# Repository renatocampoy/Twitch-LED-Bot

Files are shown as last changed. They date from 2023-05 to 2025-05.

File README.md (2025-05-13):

## Twitch LED Bot - ESP8266

Criado por Eng. Renato Campoy.

Este projeto permite que você controle um strip de LED NeoPixel via comandos no chat da Twitch, utilizando a placa ESP8266. O código é escrito em C++ e utiliza a biblioteca WiFiManager para gerenciar a conexão Wi-Fi e a biblioteca Adafruit NeoPixel para controlar o strip de LED.

<p float="center">
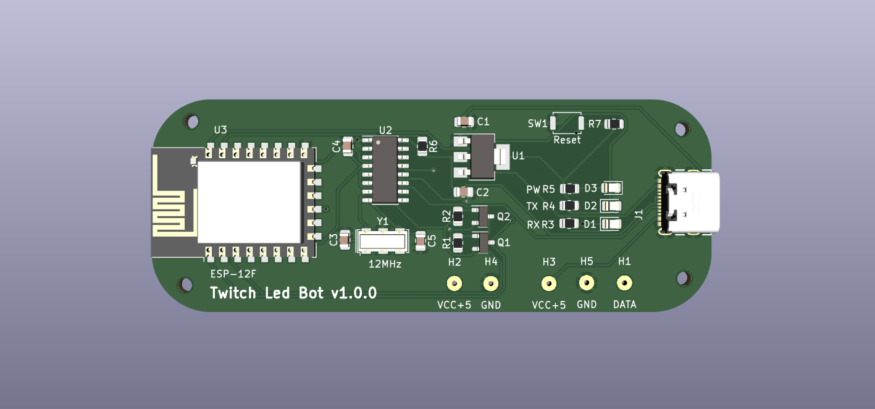
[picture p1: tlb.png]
 
</p>

## Token da Twitch

Para usar este código, você precisará de um token de OAuth da Twitch. Aqui estão as etapas para obtê-lo:

1.  Acesse [https://twitchapps.com/tmi/](https://twitchapps.com/tmi/)
2.  Clique em 'Connect' e autorize o acesso ao seu canal.
3.  Copie o token gerado. Este é o seu token OAuth, que permite que o bot envie mensagens ao seu canal.

Tenha em mente que este token é equivalente à senha da sua conta da Twitch. Não compartilhe com ninguém.

### Dependências

Você precisará das seguintes bibliotecas para usar este projeto:

-   ESP8266WiFi
-   DNSServer
-   ESP8266WebServer
-   WiFiManager
-   EEPROM
-   Adafruit_NeoPixel

Estas bibliotecas podem ser instaladas através do Gerenciador de Bibliotecas do Arduino.

## Instalação

1.  Clone este repositório.
2.  Abra o arquivo `.ino` no Arduino IDE.
3.  Carregue o código para o ESP8266.

## Configuração

1.  Ao ligar o ESP, uma rede wifi com o nome LEDBOT_AP aparecerá, conecte-se a ela.
2.  Ao conectar, aparecerá uma pagina onde você deve clicar em "Configure WIFI"
3.  Clique na sua REDE, entre com a senha.
4. Em "Nick" é o seu usuário da Twitch tudo em minúsculo 
5. Em Token você vai colocar o token gerado no tópico "Token da Twitch"

## Uso

Uma vez que o código esteja funcionando, você poderá enviar comandos para o chat da Twitch para controlar a iluminação do strip de LED. Aqui estão alguns exemplos de comandos que você pode usar:

-   `!led vermelho`: muda a cor do LED para vermelho.
-   `!led #ff00ff`: muda a cor do LED para o valor hexadecimal fornecido (neste caso, magenta).
-   `!led cores`: lista todas as cores disponíveis.

Além disso, o bot responde a comandos enviados via interface serial para reiniciar o ESP ou redefinir as configurações de WiFi ou Twitch. (vide código)

## Contribuição

Este é um projeto open-source. Se tiver alguma sugestão ou melhoria, por favor, faça um fork do repositório e envie uma pull request.

## Problemas Conhecidos

Atualmente, o bot não responde a erros do servidor da Twitch. Se você experimentar algum problema, tente reiniciar o ESP.

## Licença

Este projeto está licenciado sob a Licença GPLv3 - veja o arquivo [LICENSE](https://www.gnu.org/licenses/gpl-3.0.pt-br.html) para mais detalhes.

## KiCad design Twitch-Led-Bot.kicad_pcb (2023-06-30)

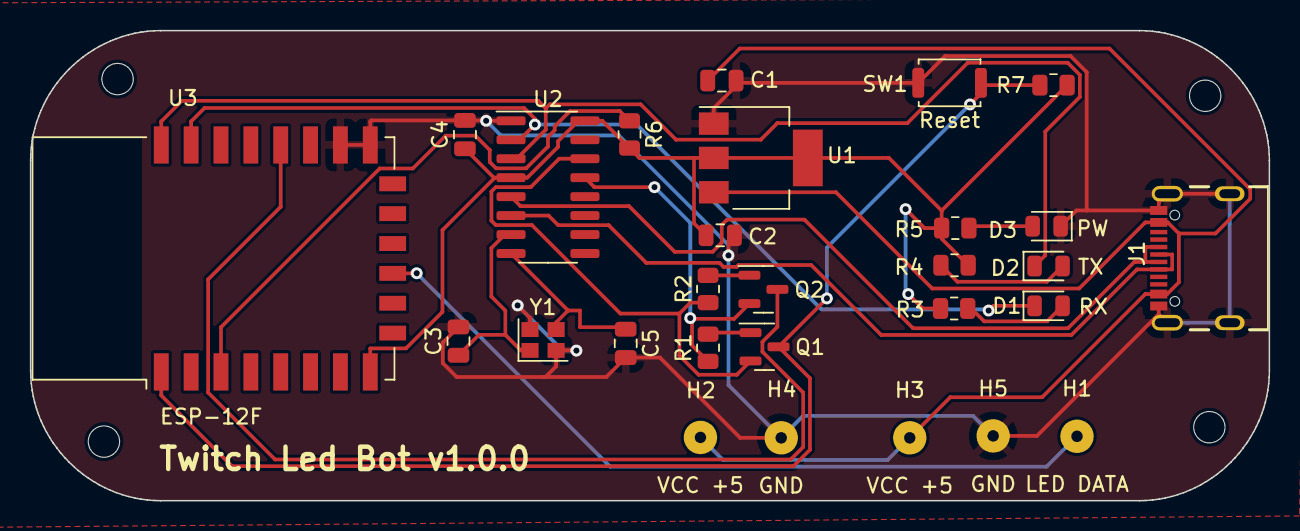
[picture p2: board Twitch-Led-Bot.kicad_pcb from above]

Board: 2 copper layers, 83.0 x 31.5 mm, 28 parts (0 on the bottom side), 20 nets.

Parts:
C1, C4: 10u; C_0805_2012Metric
C2: 100u; C_0805_2012Metric
C3, C5: 22p; C_0805_2012Metric
D1: RX; LED_0805_2012Metric
D2: TX; LED_0805_2012Metric
D3: PW; LED_0805_2012Metric
H1: LED DATA; MountingHole_2.1mm
H2, H3: VCC +5; MountingHole_2.1mm
H4, H5: GND; MountingHole_2.1mm
J1: USB4105-GF-A; GCT_USB4105-GF-A
Q1, Q2: BC847; SOT-23
R1, R2, R6, R7: 10K; R_0805_2012Metric
R3, R4, R5: 470; R_0805_2012Metric
SW1: Reset; SW_Push_SPST_NO_Alps_SKRK
U1: AMS1117-3.3; SOT-223-3_TabPin2
U2: CH340G; SOIC-16_3.9x9.9mm_P1.27mm
U3: ESP-12F; ESP-12E
Y1: 12MHz; Crystal_SMD_2520-4Pin_2.5x2.0mm

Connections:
+3V3: C2.1, C4.1, R3.2, R4.2, R5.2, R6.2, R7.2, U1.2 (VO), U2.4 (V3), U2.16 (VCC), U3.8 (VCC)
+5V: C1.1, H2.1, H3.1, J1.A4_B9 (VBUS), J1.B4_A9 (VBUS), U1.3 (VI)
CH_PD: R6.1, U3.3 (EN)
D+: J1.A6 (DP1), J1.B6 (DP2), U2.5 (UD+)
D-: J1.A7 (DN1), J1.B7 (DN2), U2.6 (UD-)
DTR: Q2.2 (E), R1.1, U2.13 (~DTR)
GND: C1.2, C2.2, C3.2, C4.2, C5.2, D3.1 (K), H4.1, H5.1, J1.A1_B12 (GND), J1.B1_A12 (GND), J1.S1 (SHELL_GND), J1.S2 (SHELL_GND), J1.S3 (SHELL_GND), J1.S4 (SHELL_GND), SW1.1, U1.1 (GND), U2.1 (GND), U3.15 (GND), U3.16 (GPIO15), Y1.2, Y1.4
IO0: Q2.3 (C), U3.18 (GPIO0)
IO9: H1.1, U3.11 (GPIO9)
unnamed: C3.1, U2.7 (XI), Y1.1
unnamed: C5.1, U2.8 (XO), Y1.3
unnamed: D1.2 (A), R3.1
unnamed: D2.2 (A), R4.1
unnamed: D3.2 (A), R5.1
unnamed: Q1.1 (B), R1.2
unnamed: Q2.1 (B), R2.2
RST: Q1.3 (C), R7.1, SW1.2, U3.1 (~RST)
RTS: Q1.2 (E), R2.1, U2.14 (~RTS)
RX: D1.1 (K), U2.2 (TXD), U3.21 (GPIO3/RXD)
TX: D2.1 (K), U2.3 (RXD), U3.22 (GPIO1/TXD)

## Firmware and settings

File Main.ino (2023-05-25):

/*
 * Twitch LED Bot - ESP8266
 * 
 * Desenvolvido por: Eng. Renato Campoy - http://campoy.eng.br
 * Versão: 1.0.0
 * Data: 25/05/2023
 * 
 * Licença: GPLv3
 * 
 * O código é livre para ser usado, modificado e distribuído,
 * desde que a atribuição seja feita ao autor original.
 */

#include <ESP8266WiFi.h>  // Importa a biblioteca para WiFi do ESP8266
#include <DNSServer.h>  // Importa a biblioteca para DNS Server
#include <ESP8266WebServer.h>  // Importa a biblioteca para Web Server do ESP8266
#include <WiFiManager.h>  // Importa a biblioteca para gerenciamento de WiFi
#include <EEPROM.h>  // Importa a biblioteca para armazenamento EEPROM
#include <Adafruit_NeoPixel.h>  // Importa a biblioteca para controle de LEDs NeoPixel

#define EEPROM_SIZE 512  // Define o tamanho da EEPROM
#define LED_PIN D8  // Define o pino onde o LED está conectado
#define LED_COUNT 200  // Define o número de LEDs no strip

// Define uma estrutura para armazenar as credenciais da Twitch
struct {
  char nick[40];
  char token[40];
}
eepromData;

// Define os parâmetros do WiFi Manager para configurar as credenciais da Twitch
WiFiManagerParameter customNick("nick", "Nick", "", 40);
WiFiManagerParameter customToken("token", "Token", "", 40);

// Define as configurações do servidor da Twitch
const char * server = "irc.chat.twitch.tv";
const int port = 6667;

// Define o cliente WiFi e o WiFi Manager
WiFiClient client;
WiFiManager wifiManager;

// Define a configuração do strip de LEDs
Adafruit_NeoPixel strip(LED_COUNT, LED_PIN, NEO_GRB + NEO_KHZ800);

// Função de callback para salvar as configurações na EEPROM quando a configuração do WiFi for concluída
void saveConfigCallback() {
  Serial.println("Deveria salvar para a EEPROM agora");

  strcpy(eepromData.nick, customNick.getValue());  // Copia o nick da Twitch para a estrutura
  strcpy(eepromData.token, customToken.getValue());  // Copia o token da Twitch para a estrutura

  EEPROM.put(0, eepromData);  // Grava a estrutura na EEPROM
  EEPROM.commit();  // Comita as alterações na EEPROM
}

// Configuração inicial do ESP8266
void setup() {
  Serial.begin(115200);  // Inicia a comunicação serial
  EEPROM.begin(EEPROM_SIZE);  // Inicia a EEPROM

  EEPROM.get(0, eepromData);  // Recupera as credenciais da Twitch da EEPROM
  Serial.println("Dados carregados da EEPROM:");
  Serial.println(eepromData.nick);  // Imprime o nick
  Serial.println(eepromData.token);  // Imprime o token

  // Se as credenciais da Twitch não estiverem configuradas, reseta as configurações do WiFi Manager
  if (String(eepromData.nick).length() == 0 || String(eepromData.token).length() == 0) {
    wifiManager.resetSettings();
  }

  // Configura os parâmetros do WiFi Manager com as credenciais da Twitch
  customNick.setValue(eepromData.nick, 40);
  customToken.setValue(eepromData.token, 40);

  // Configura a função de callback para salvar as configurações
  wifiManager.setSaveConfigCallback(saveConfigCallback);

  // Adiciona os parâmetros ao WiFi Manager
  wifiManager.addParameter( & customNick);
  wifiManager.addParameter( & customToken);

  // Configura o timeout do WiFi Manager
  wifiManager.setTimeout(180);

  // Tenta conectar automaticamente ao WiFi
  if (!wifiManager.autoConnect("LEDBOT_AP")) {
    Serial.println("Falha na conexão WiFi... Reiniciando.");  // Se falhar, imprime uma mensagem e reinicia o ESP8266
    delay(3000);
    ESP.restart();
  }

  Serial.println("Conectado!");  // Se conectar, imprime uma mensagem

  // Inicia o strip de LEDs
  strip.begin();
  strip.show();
  
  Serial.println("");
  Serial.println("WiFi connected");

  Serial.println("Starting connection to server...");
  if (client.connect(server, port)) {
    while (client.connected()) {
      Serial.print(client.availableForWrite());
      Serial.print(".");
      client.print("PASS " + String(eepromData.token) + "\r\n");
      client.print("NICK " + String(eepromData.nick) + "\r\n");
      client.print("JOIN #" + String(eepromData.nick) + "\r\n");
      delay(1000);
    }
    Serial.println("connected to server");
  }
}

// Função principal que será executada continuamente
void loop() {
  // Adicionado para contornar problemas de conexão com a twitch
  if (!client.connected()) {
    if (client.connect(server, port)) {
      Serial.print(".");
      client.print("PASS " + String(eepromData.token) + "\r\n");
      client.print("NICK " + String(eepromData.nick) + "\r\n");
      client.print("JOIN #" + String(eepromData.nick) + "\r\n");
    }
  }

  // Comandos via SERIAL
  if (Serial.available()) {
    String command = Serial.readStringUntil('\n');
    if (command.startsWith("reset esp")) {
      Serial.println("Comando recebido: Reiniciando o ESP.");
      ESP.restart();
    } else if (command.startsWith("reset wifi")) {
      Serial.println("Comando recebido: Reiniciando configurações de wifi.");
      wifiManager.resetSettings();
    } else if (command.startsWith("reset twitch")) {
      Serial.println("Comando recebido: Reiniciando configurações da twitch.");
      strcpy(eepromData.token, "");
      strcpy(eepromData.nick, "");
      EEPROM.put(0, eepromData);
      EEPROM.commit();
    } else if (command.startsWith("reset all")) {
      Serial.println("Comando recebido: Reiniciando tudo.");
      strcpy(eepromData.token, "");
      strcpy(eepromData.nick, "");
      EEPROM.put(0, eepromData);
      EEPROM.commit();
      wifiManager.resetSettings();
      ESP.restart();
    }
  }

  while (client.available()) {
    String line = client.readStringUntil('\r');
    int commandIndex = line.indexOf("!led");
    if (commandIndex != -1) {
      String command = line.substring(commandIndex, commandIndex + 4);
      String variable = line.substring(commandIndex + 5);
      String cor = variable;

      variable.toLowerCase();
      cor.toLowerCase();

      Serial.println("Comando recebido: " + command);
      Serial.println("Com a variavel: " + variable);

      // Cores legendas
      if (variable == "cores") {
        String cores = "vermelho, amarelo, ciano, magenta, verde, azul, ciano, magenta, branco, preto, laranja e rosa, ou uma cor em hex exemplo: #03cffc";
        client.print("PRIVMSG #" + String(eepromData.nick) + " :" + "As cores disponíveis são: " + cores + "\r\n");
      }

      // Cores padrões
      if (cor == "vermelho") {
        setColor(255, 0, 0, variable);
      } else if (cor == "amarelo") {
        setColor(255, 255, 0, variable);
      } else if (cor == "ciano") {
        setColor(0, 255, 255, variable);
      } else if (cor == "magenta") {
        setColor(255, 0, 255, variable);
      } else if (cor == "verde") {
        setColor(0, 255, 0, variable);
      } else if (cor == "azul") {
        setColor(0, 0, 255, variable);
      } else if (cor == "ciano") {
        setColor(0, 255, 255, variable);
      } else if (cor == "magenta") {
        setColor(255, 0, 255, variable);
      } else if (cor == "branco") {
        setColor(255, 255, 255, variable);
      } else if (cor == "preto") {
        setColor(0, 0, 0, variable);
      } else if (cor == "laranja") {
        setColor(255, 165, 0, variable);
      } else if (cor == "rosa") {
        setColor(255, 105, 180, variable);
      } else {
        setColor(0, 0, 0, variable);
      }

      // Cores em HEX
      int variableIndex = variable.indexOf("#");
      if (variableIndex != -1) {
        int r, g, b;
        hexToRgb(variable, r, g, b);
        setColor(r, g, b, variable);
      }

      strip.show();

    }
  }
}

// Função para configurar a cor dos LEDs
void setColor(int red, int green, int blue, String variable) {
  for (int i = 0; i < strip.numPixels(); i++) {
    strip.setPixelColor(i, strip.Color(red, green, blue));
  }

  if (variable != "cores") {
    client.print("PRIVMSG #" + String(eepromData.nick) + " :" + "Legal, a cor foi alterada! \r\n");
  }
}

// Função para converter uma cor em formato hexadecimal para RGB
void hexToRgb(String hexColor, int & r, int & g, int & b) {
  char charBuff[7];
  hexColor.toCharArray(charBuff, sizeof(charBuff));
  sscanf(charBuff, "%02x%02x%02x", & r, & g, & b);
}

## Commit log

2023-06-29 Bug correction v.1.0.1
    Correction in the wiring diagram with the microcontroller connecting GP015 to GND
    [Twitch-Led-Bot.kicad_pcb, Twitch-Led-Bot.kicad_sch]
2023-06-30 Bug correction v.1.0.2
    RX LED has problems on the trail in the schematic
    [Twitch-Led-Bot.kicad_pcb]

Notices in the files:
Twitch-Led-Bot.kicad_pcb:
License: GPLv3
